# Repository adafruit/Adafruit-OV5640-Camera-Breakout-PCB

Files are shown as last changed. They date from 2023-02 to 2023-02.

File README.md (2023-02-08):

## Adafruit OV5640 Camera Breakout - 120 Degree Lens PCB

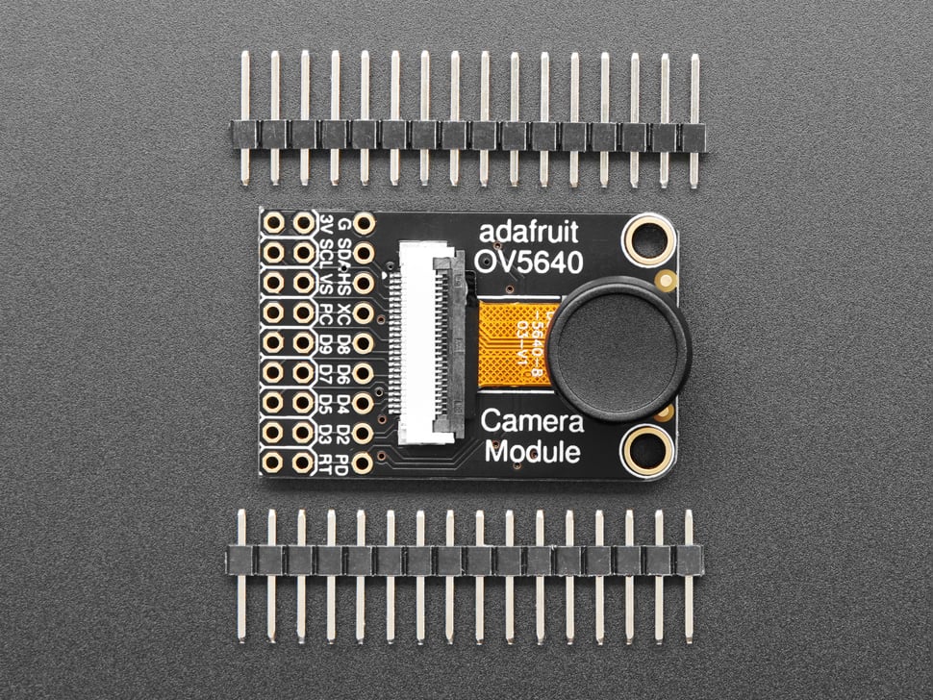
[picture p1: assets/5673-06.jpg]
<a href="http://www.adafruit.com/products/5673"><br/>
Click here to purchase one from the Adafruit shop</a>

PCB files for the Adafruit OV5640 Camera Breakout - 120 Degree Lens. 

Format is EagleCAD schematic and board layout
* https://www.adafruit.com/product/5673

### Description

Hobby-level microcontrollers are finally getting big and powerful enough to start handling camera modules that historically would have required a full computer or FPGA to handle. The RP2040 and ESP32-Sx series of chips, for example, have enough pins to communicate with the 8-bit data output, DMA to quickly grab a frame, and the necessary RAM to buffer a raw snapshot. Now all we need is a nice camera module to make interfacing easy!

This Adafruit OV5640 Camera Breakout with 120 Degree Lens has a nice quality OV5640 camera with a 5 Megapixel sensor element, 120-degree wide angle lens, and all the support circuitry you need. We looked at existing camera modules and while this breakout board is backwards compatible, we made some improvements:

* Standard 2x9 header if you want it, but also a duplicated header strip 0.3" apart so you can plug it into a breadboard or perfboard 
* Selectable external or internal 24MHz "XCLK" clock generation - save one gpio pin, or just have a nice stable 24 MHz signal even if your microcontroller can't generate it for you.
* Heat-sinking camera area with exposed ground pad, with lots of vias for good thermal transfer. Helpful for when doing continuous encoding and reducing thermal image drift.
* Optional VMotor 3.3V power jumper on DATA1, for auto-focusing camera modules
* 3.3V power-good LED on back that can be disabled

### License

Adafruit invests time and resources providing this open source design, please support Adafruit and open-source hardware by purchasing products from [Adafruit](https://www.adafruit.com)!

Designed by Limor Fried/Ladyada for Adafruit Industries.

Creative Commons Attribution/Share-Alike, all text above must be included in any redistribution. 
See license.txt for additional details.

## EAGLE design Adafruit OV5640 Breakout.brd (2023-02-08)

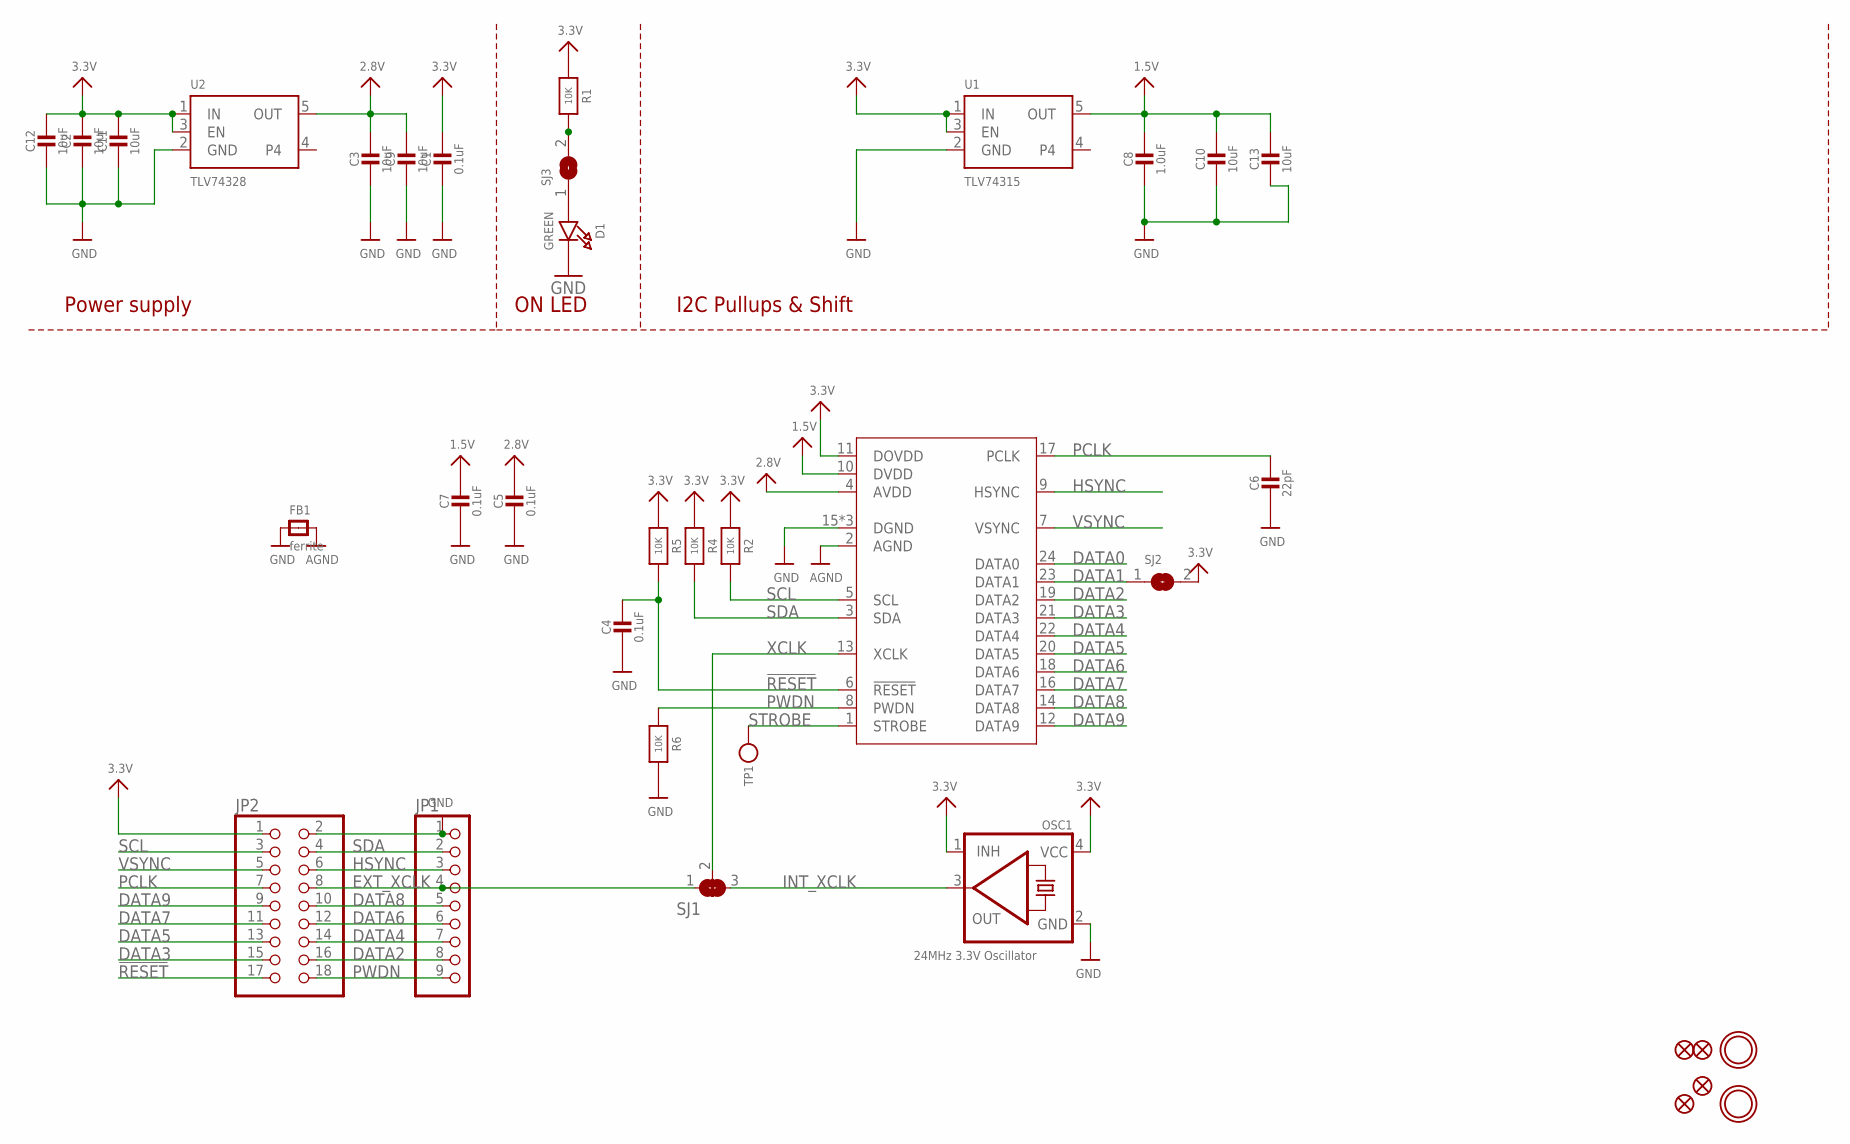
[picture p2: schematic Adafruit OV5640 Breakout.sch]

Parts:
C1, C4, C5, C7: 0.1uF; 0603-NO
C2, C3, C9, C10, C11, C12, C13: 10uF; 0805-NO
C6: 22pF; 0603-NO
C8: 1.0uF; 0603-NO
D1: GREEN; CHIPLED_0603_NOOUTLINE
FB1: ferrite; 0603-NO
FID1, FID2, FID3, FID4: FIDUCIAL_1MM
JP1: HEADER-1X970MIL; 1X09_ROUND_70
JP2: PINHD-2X9-BIG; 2X09-BIG
OSC1: 24MHz 3.3V Oscillator; OSC_3.2X2.5MM
R1, R2, R4, R5, R6: 10K; 0603-NO
SJ1: SOLDERJUMPER_2WAY; SOLDERJUMPER_2WAY_OPEN_NOPASTE
SJ2: SOLDERJUMPER; SOLDERJUMPER_ARROW_NOPASTE
SJ3: SOLDERJUMPERCLOSED; SOLDERJUMPER_CLOSEDWIRE
TP1: TESTPOINTROUND1.5MM; TESTPOINT_ROUND_1.5MM
U1: TLV74315; SOT23-5; JLC_ROTATION 0
U2: TLV74328; SOT23-5; JLC_ROTATION 0
U$1, U$17: MOUNTINGHOLE3.0THIN; MOUNTINGHOLE_3.0_PLATEDTHIN
X1: CAMERA_OV2640; OV2640FSL

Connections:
1.5V: C7.1, C8.1, C10.1, C13.1, U1.5 (OUT), X1.10 (DVDD)
2.8V: C3.1, C5.1, C9.1, U2.5 (OUT), X1.4 (AVDD)
3.3V: C1.1, C2.1, C11.1, C12.1, JP2.1, OSC1.1 (INH), OSC1.4 (VCC), R1.1, R2.1, R4.1, R5.1, SJ2.2, U1.1 (IN), U1.3 (EN), U2.1 (IN), U2.3 (EN), X1.11 (DOVDD)
!RESET: C4.1, JP2.17, R5.2, X1.6 (!RESET)
AGND: FB1.2, X1.2 (AGND)
DATA0: X1.24 (DATA0)
DATA1: SJ2.1, X1.23 (DATA1)
DATA2: JP1.8, JP2.16, X1.19 (DATA2)
DATA3: JP2.15, X1.21 (DATA3)
DATA4: JP1.7, JP2.14, X1.22 (DATA4)
DATA5: JP2.13, X1.20 (DATA5)
DATA6: JP1.6, JP2.12, X1.18 (DATA6)
DATA7: JP2.11, X1.16 (DATA7)
DATA8: JP1.5, JP2.10, X1.14 (DATA8)
DATA9: JP2.9, X1.12 (DATA9)
EXT_XCLK: JP1.4, JP2.8, SJ1.1
GND: C1.2, C2.2, C3.2, C4.2, C5.2, C6.2, C7.2, C8.2, C9.2, C10.2, C11.2, C12.2, C13.2, D1.C, FB1.1, JP1.1, JP2.2, OSC1.2 (GND), R6.2, U1.2 (GND), U2.2 (GND), X1.15 (DGND), X1.SPRT1 (DGND), X1.SPRT2 (DGND)
HSYNC: JP1.3, JP2.6, X1.9 (HSYNC)
INT_XCLK: OSC1.3 (OUT), SJ1.3
unnamed: R1.2, SJ3.2
unnamed: D1.A, SJ3.1
PCLK: C6.1, JP2.7, X1.17 (PCLK)
PWDN: JP1.9, JP2.18, R6.1, X1.8 (PWDN)
SCL: JP2.3, R2.2, X1.5 (SCL)
SDA: JP1.2, JP2.4, R4.2, X1.3 (SDA)
STROBE: TP1.P$1, X1.1 (STROBE)
VSYNC: JP2.5, X1.7 (VSYNC)
XCLK: SJ1.2, X1.13 (XCLK)

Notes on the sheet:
I2C Pullups & Shift
ON LED
Power supply

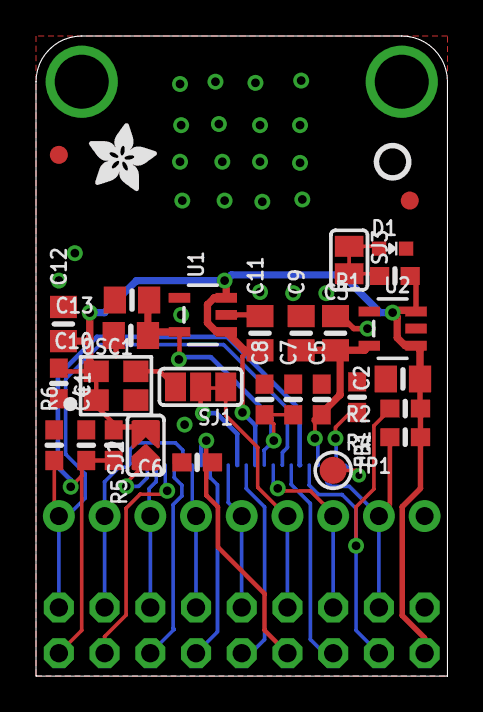
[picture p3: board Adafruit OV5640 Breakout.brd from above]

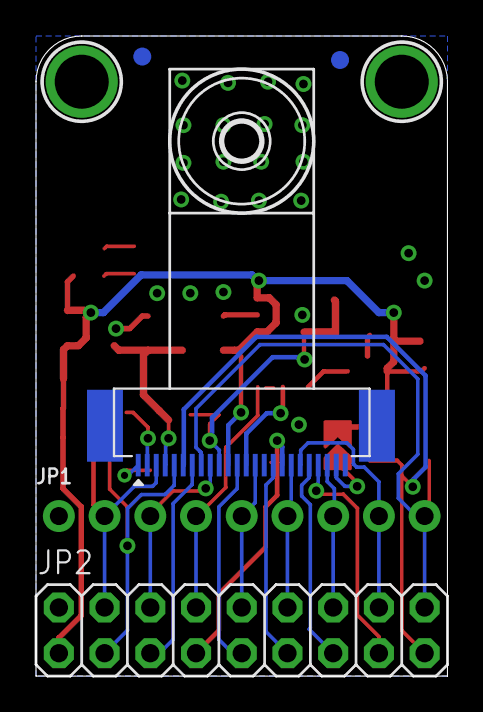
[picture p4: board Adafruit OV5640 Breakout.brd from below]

Board: 2 copper layers, 22.9 x 35.6 mm, 64 parts (27 on the bottom side), 27 nets.

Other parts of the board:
PLABEL0: PLABEL0
PLABEL1: PLABEL1
PLABEL2: PLABEL2
PLABEL3: PLABEL3
PLABEL4: PLABEL4
PLABEL5: PLABEL5
PLABEL6: PLABEL6
PLABEL7: PLABEL7
PLABEL8: PLABEL8
PLABEL9: PLABEL9
PLABEL10: PLABEL10
PLABEL11: PLABEL11
PLABEL12: PLABEL12
PLABEL13: PLABEL13
PLABEL14: PLABEL14
PLABEL15: PLABEL15
PLABEL16: PLABEL16
PLABEL17: PLABEL17
PLABEL18: PLABEL18
PLABEL19: PLABEL19
PLABEL20: PLABEL20
PLABEL21: PLABEL21
PLABEL22: PLABEL22
PLABEL23: PLABEL23
PLABEL24: PLABEL24
PLABEL25: PLABEL25
U$22: ADAFRUIT_3.5MM
U$25: PCBFEAT-REV-040

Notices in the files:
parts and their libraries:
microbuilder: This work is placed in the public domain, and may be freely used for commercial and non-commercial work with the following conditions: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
